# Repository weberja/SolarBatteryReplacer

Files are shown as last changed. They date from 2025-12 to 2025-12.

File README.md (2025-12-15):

# Battery Replacer
The goal of this project is to have a solar powered lithium charger which can replace three AA Batteries in garden lamps.

This started as a project to tinker around with PCBs and have a project with a real goal. In the end i recreated a basically the [Adafruit bq25185 USB / DC / Solar Charger](https://www.adafruit.com/product/6106?srsltid=AfmBOopIVtmkb0ocQaOu4vhrrnbkDsrhC9rcjArDRcQqwAPNf7DQO3vv).

**Key points:**
* Lithium Charger for 4.2V
* MPPT for the poor man - AKA not a full implementation for MPPT but atleast something
* USB Charger
* Replace 3 AA Batteries
* Switch on if it gets dark and run until the battery under voltage protection is triggered

**Voltage & Amps:**
1. 5V á 500 mA Solar panel
2. 5V á 500 mA USB Input
3. 4.2V 500 mA Charging of Lithium Battery
4. 4.2V or lower á 1A Output

## Schematics
Main Component is a BQ25185. It checks all the points. With a 4.2V lithium battery it can also replace the 3 AA Batteries.

One special feature is the use of the LM66200, which is a "Ideal Dual-Diode" which can handle only up to 5.5V. Regarding the planed input and output voltage this device is better then diodes.

To be able to use solar panels with a voltage greater then 5V also two diodes are included. These can be activated with solder jumpers and the LM66200 needs to deactivated with the same solder jumper. See JP5 and JP3.

A different VSET and ISET can be done via the solder jumper JP1 and JP2. The existing resistor needs to be desoldered.

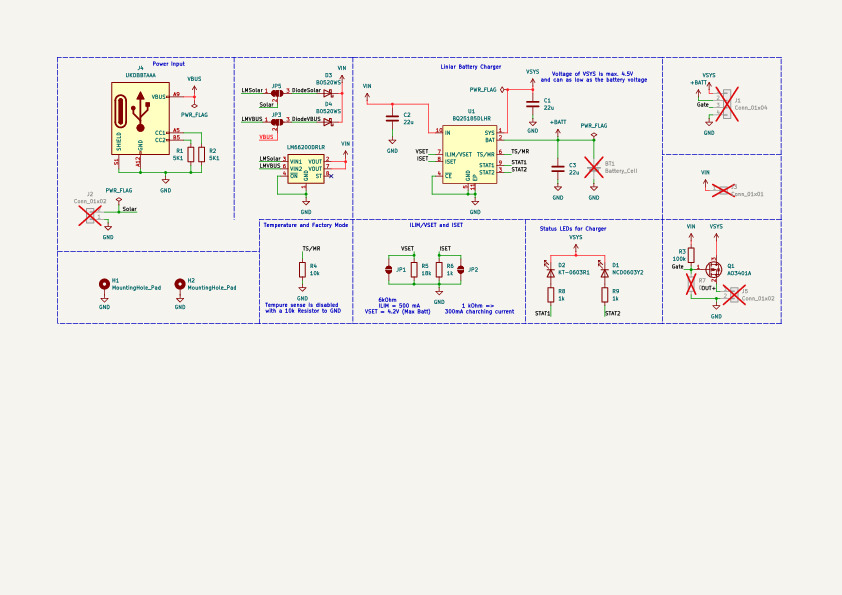
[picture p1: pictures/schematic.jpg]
Schematic


## PCB Design
The design should be as small as possible and have big enough components to tinker around. So it could be smaller but for me it is okay.

"-S+" is the input from the solar cells.
"LED" is the output to the garden LED light. (Voltage of the Battery of of the Input)
To the right of the LED, the Battery connector is provided.

### Front
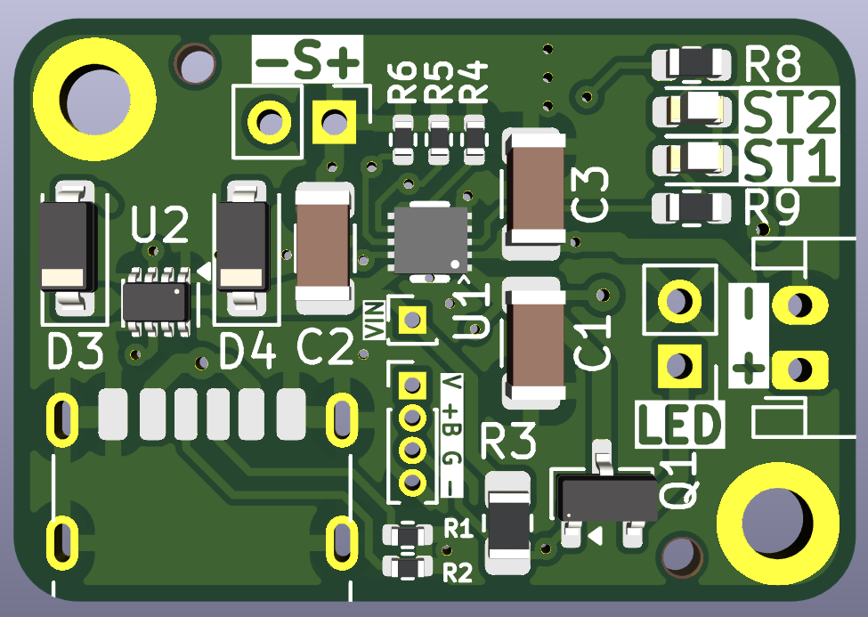
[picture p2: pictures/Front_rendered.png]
PCB Front rendered

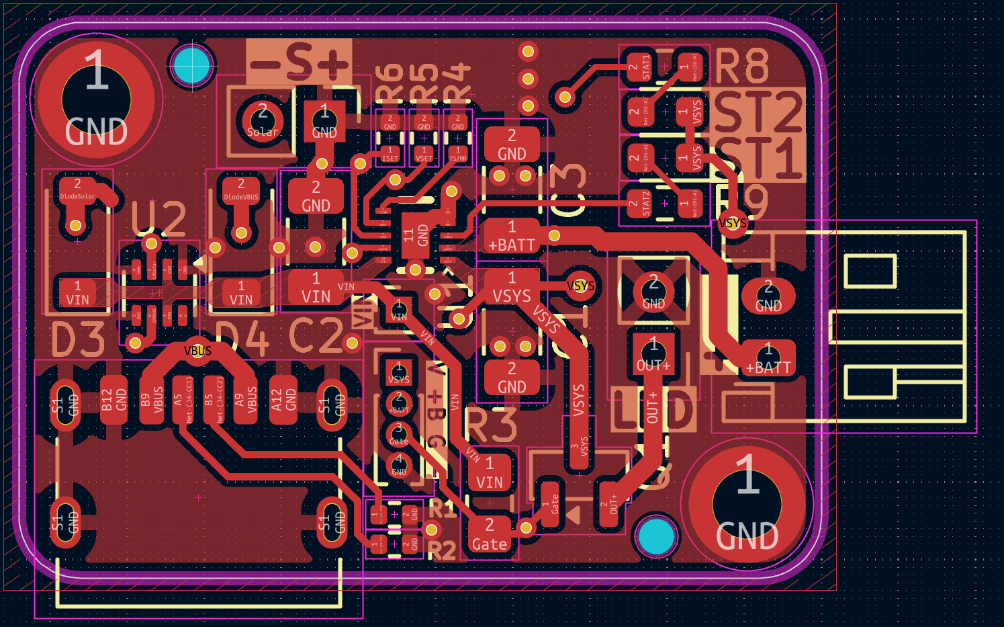
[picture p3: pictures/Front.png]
PCB Front


### Back
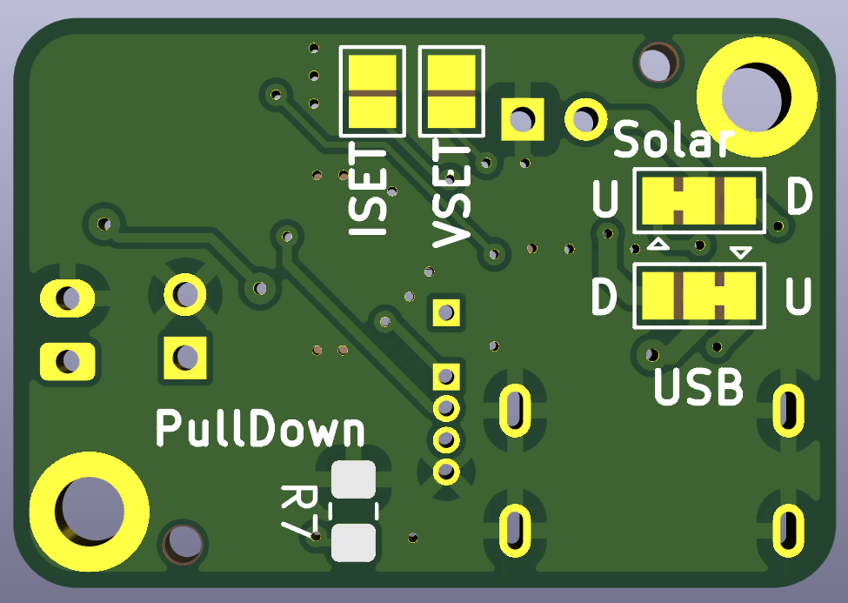
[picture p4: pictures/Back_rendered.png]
PCB Back rendered

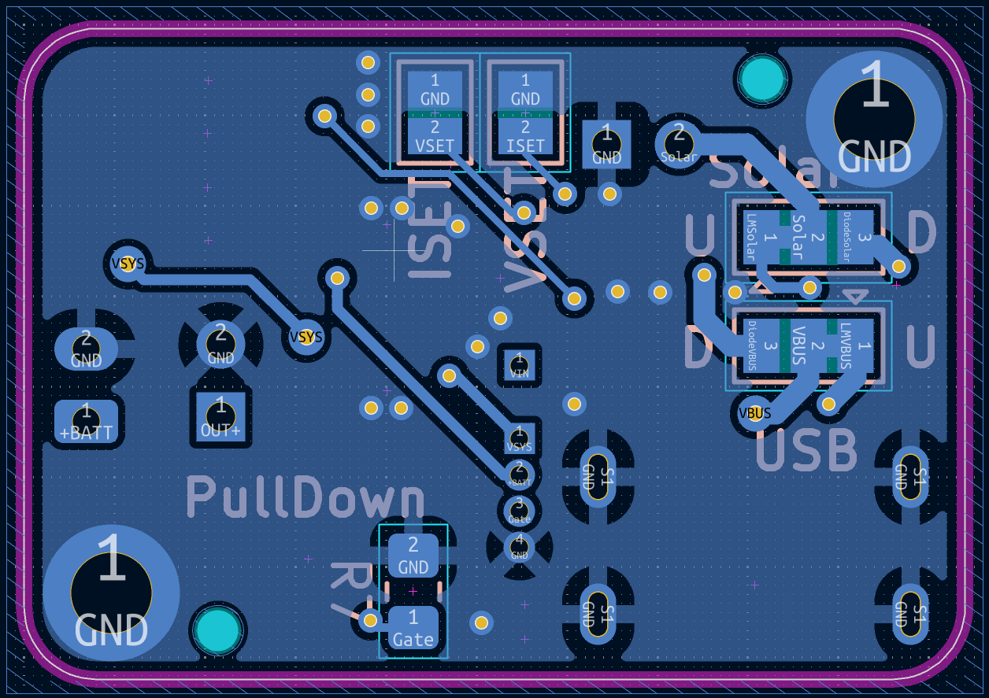
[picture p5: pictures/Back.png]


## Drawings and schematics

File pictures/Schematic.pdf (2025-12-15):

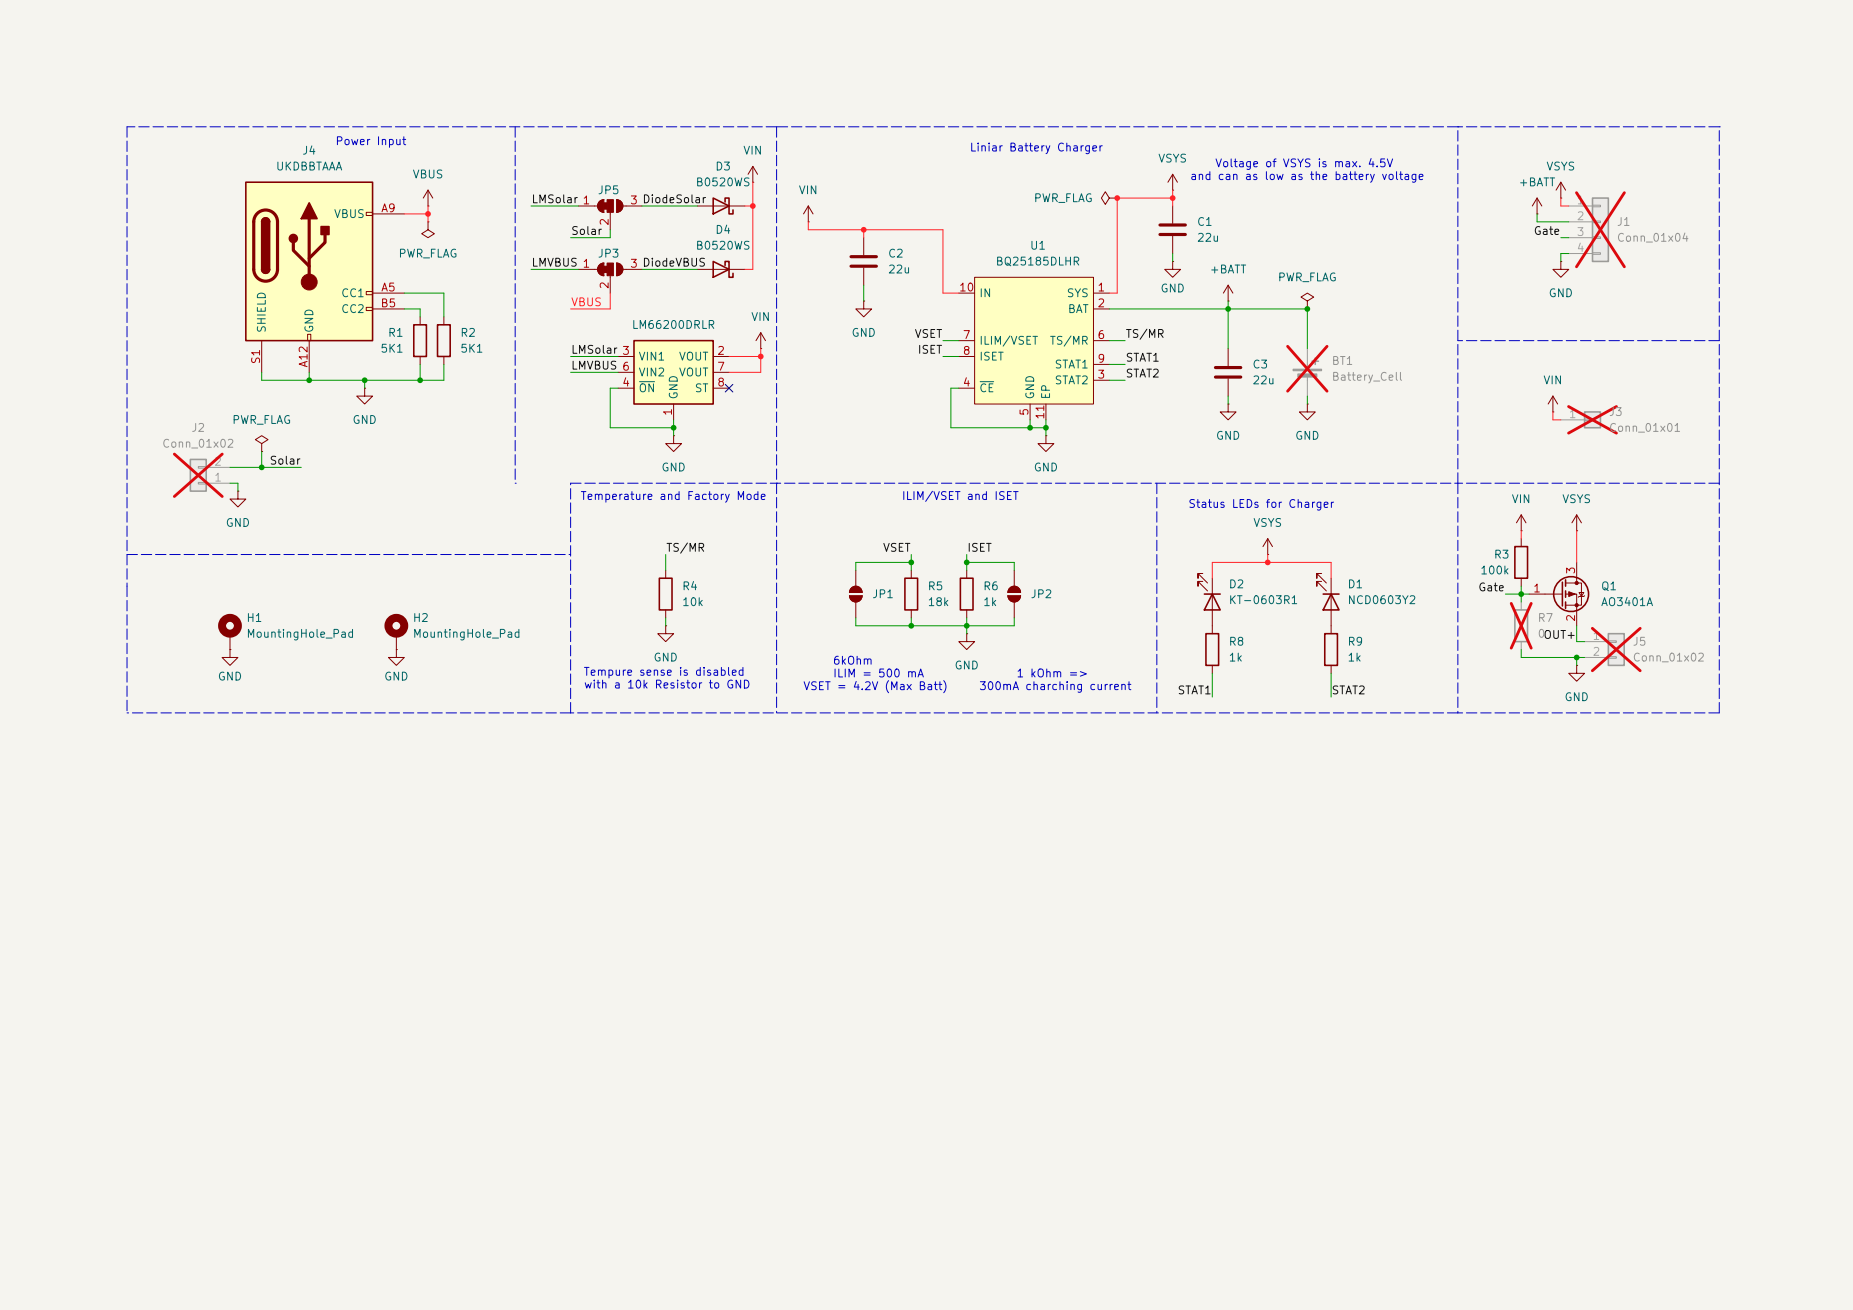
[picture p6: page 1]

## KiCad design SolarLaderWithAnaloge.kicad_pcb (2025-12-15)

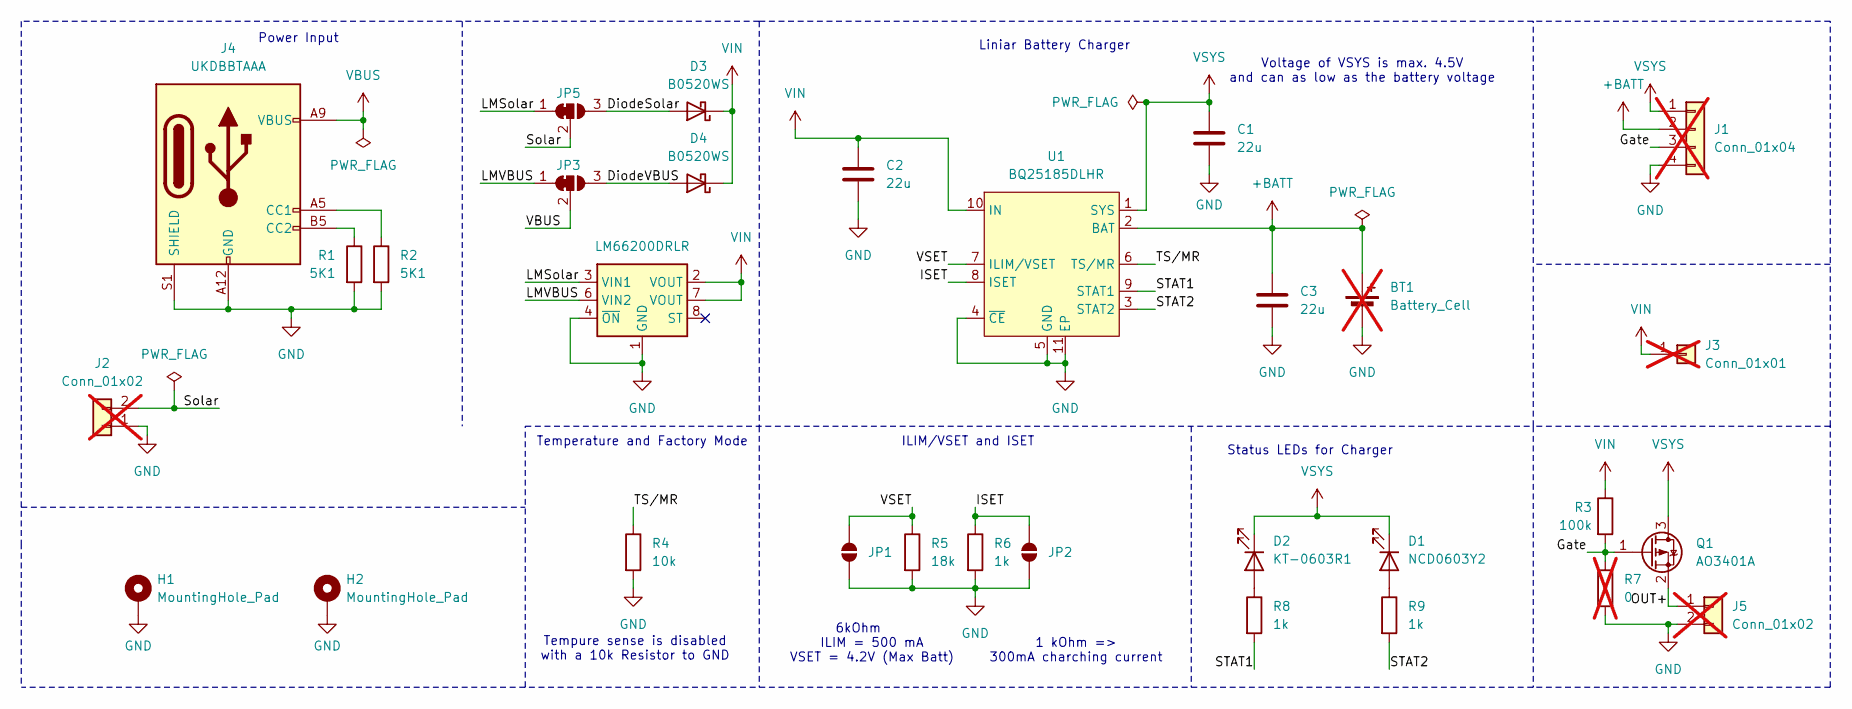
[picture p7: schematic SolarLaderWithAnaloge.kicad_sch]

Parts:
BT1: Battery_Cell; JST_PH_S2B-PH-K_1x02_P2.00mm_Horizontal; not fitted
C1, C2, C3: 22u; C_1206_3216Metric
D1: NCD0603Y2; LED_0603_1608Metric
D2: KT-0603R1; LED_0603_1608Metric
D3, D4: B0520WS; D_SOD-123
H1, H2: MountingHole_Pad; MountingHole_2.2mm_M2_DIN965_Pad
J1: Conn_01x04; PinHeader_1x04_P1.00mm_Vertical; not fitted
J2, J5: Conn_01x02; PinHeader_1x02_P2.00mm_Vertical; not fitted
J3: Conn_01x01; PinHeader_1x01_P1.00mm_Vertical; not fitted
J4: UKDBBTAAA; USB_C_Receptacle_HRO_TYPE-C-31-M-17
JP1, JP2: SolderJumper_2_Open; SolderJumper-2_P1.3mm_Open_Pad1.0x1.5mm
JP3, JP5: SolderJumper_3_Bridged12; SolderJumper-3_P1.3mm_Bridged12_Pad1.0x1.5mm
Q1: AO3401A; SOT-23
R1, R2: 5K1; R_0402_1005Metric
R3: 100k; R_0805_2012Metric_Pad1.20x1.40mm_HandSolder
R4: 10k; R_0402_1005Metric
R5: 18k; R_0402_1005Metric
R6: 1k; R_0402_1005Metric
R7: 0; R_0805_2012Metric_Pad1.20x1.40mm_HandSolder; not fitted
R8, R9: 1k; R_0603_1608Metric
U1: BQ25185DLHR; WSON-10_L2.2-W2.0-P0.40-BL-EP_TI_DLH0010A; LCSC Part C19725033
U2: LM66200DRLR; SOT-8 TI

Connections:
+BATT: BT1.1 (+), C3.1, J1.2, U1.2 (BAT)
/DiodeSolar: D3.2 (A), JP5.3 (B)
/DiodeVBUS: D4.2 (A), JP3.3 (B)
/Gate: J1.3, Q1.1 (G), R3.2, R7.1
/ISET: JP2.2 (B), R6.1, U1.8 (ISET)
/LMSolar: JP5.1 (A), U2.3 (VIN1)
/LMVBUS: JP3.1 (A), U2.6 (VIN2)
/OUT+: J5.1, Q1.2 (S)
/STAT1: R8.2, U1.9 (STAT1)
/STAT2: R9.2, U1.3 (STAT2)
/Solar: J2.2, JP5.2 (C)
/TS/MR: R4.1, U1.6 (TS/MR)
/VSET: JP1.2 (B), R5.1, U1.7 (ILIM/VSET)
GND: BT1.2 (-), C1.2, C2.2, C3.2, H1.1, H2.1, J1.4, J2.1, J4.A12 (GND), J4.B12 (GND), J4.S1 (SHIELD), J5.2, JP1.1 (A), JP2.1 (A), R1.2, R2.2, R4.2, R5.2, R6.2, R7.2, U1.4 (~CE), U1.5 (GND), U1.11 (EP), U2.1 (GND), U2.4 (~ON), U2.5 (GND)
unnamed: D1.2 (A), R9.1
unnamed: D2.2 (A), R8.1
unnamed: J4.A5 (CC1), R2.1
unnamed: J4.B5 (CC2), R1.1
VBUS: J4.A9 (VBUS), J4.B9 (VBUS), JP3.2 (C)
VIN: C2.1, D3.1 (K), D4.1 (K), J3.1, R3.1, U1.10 (IN), U2.2 (VOUT), U2.7 (VOUT)
VSYS: C1.1, D1.1 (K), D2.1 (K), J1.1, Q1.3 (D), U1.1 (SYS)

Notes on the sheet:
Status LEDs for Charger
1 kOhm => 300mA charching current
Power Input
ILIM/VSET and ISET
Voltage of VSYS is max. 4.5V and can as low as the battery voltage
Liniar Battery Charger
Temperature and Factory Mode
Tempure sense is disabled with a 10k Resistor to GND
6kOhm ILIM = 500 mA VSET = 4.2V (Max Batt)

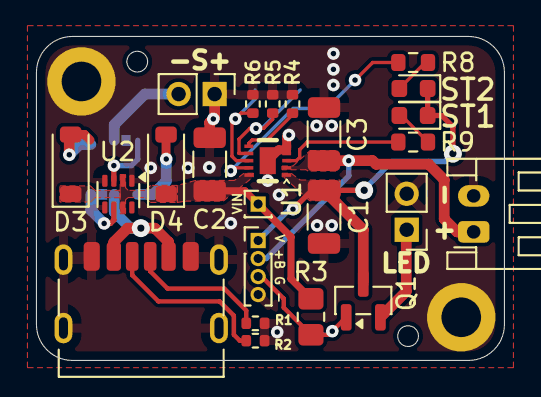
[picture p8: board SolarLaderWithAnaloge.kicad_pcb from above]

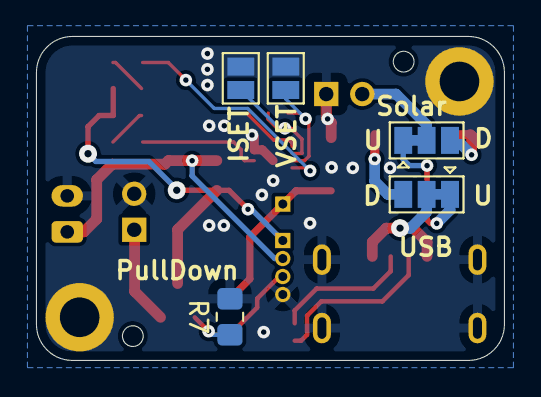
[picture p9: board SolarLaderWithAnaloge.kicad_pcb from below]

Board: 2 copper layers, 26.0 x 18.0 mm, 31 parts (5 on the bottom side), 21 nets.

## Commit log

2025-09-05 Stand mit 1.5V
    [Solarlader.kicad_pcb, Solarlader.kicad_sch]
2025-09-09 Saved between
    [Solarlader.kicad_pcb, Solarlader.kicad_sch]
2025-09-14 REV2 - only 0603 components and mounting hols
    [SolarLader.kicad_pcb, SolarLader.kicad_sch, Solarlader.kicad_pcb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]
2025-12-15 PreRelease 0.1
    [SolarLader.kicad_pcb, SolarLader.kicad_sch, SolarLaderWithAnaloge.kicad_pcb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]
2025-12-15 Update the Jumper for the input
    [SolarLaderWithAnaloge.kicad_pcb, SolarLaderWithAnaloge.kicad_sch]
